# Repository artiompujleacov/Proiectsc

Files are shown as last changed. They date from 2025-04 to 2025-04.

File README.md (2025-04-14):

# README - OpenBook E-Reader

**Autor: Artiom Pujleacov**

## Prezentare Generală

OpenBook este un dispozitiv e-reader open-source, bazat pe microcontrollerul ESP32-C6. Acesta integrează un ecran e-paper de 7.5 inch, senzori de mediu (BME680), un sistem de gestionare a bateriei și conectivitate prin Wi-Fi și USB-C. Acest document oferă detalii despre arhitectura hardware, componentele utilizate și conexiunile lor.

---

## Diagramă de Bloc



# Lista de componente

| Cantitate | Componentă | Valoare | Descriere | Carcasă | Reper | Link Cumpărare | Datasheet |
|---|---|---|---|---|---|---|---|
| 1 | ADAFRUIT_LEDCHIP-LED0603 | - | LED | ADAFRUIT_CHIP-LED0603 | CHG_LED | [link](https://www.mouser.com/ProductDetail/Adafruit/CHIP-LED0603) | [datasheet](https://www.mouser.com/datasheet/2/737/CHIP-LED0603-1877199.pdf) |
| 1 | SJ | - | SMD solder JUMPER | SJ | SJ1 | [link](https://www.mouser.com/ProductDetail/TE-Connectivity/1-2176091-2) | [datasheet](https://www.mouser.com/datasheet/2/418/1-2176091-2-1817091.pdf) |
| 1 | ESP32_WROVER_EAGLE-LTSPICE_RR0402  | 0.47Ω | Rezistor | ESP32_WROVER_EAGLE-LTSPICE_R0402| R3 | [link](https://www.mouser.com/ProductDetail/Vishay/CRCW04020047ZRT7) | [datasheet](https://www.mouser.com/datasheet/2/427/crcwce-1764191.pdf) |
| 1 | ESP32_WROVER_EAGLE-LTSPICE_RR0402  | 100KΩ | Rezistor | ESP32_WROVER_EAGLE-LTSPICE_R0402| R1_PWRUSB | [link](https://www.mouser.com/ProductDetail/Vishay/CRCW0402100KFKED) | [datasheet](https://www.mouser.com/datasheet/2/427/crcwce-1764191.pdf) |
| 8 | EAGLE-LTSPICE_CC0402 | 100nF | Condensator | EAGLE-LTSPICE_C0402 | C1, C2, C4_USB, C6, C8, C9, C10, C_DELAY | [link](https://www.mouser.com/ProductDetail/Murata/GRM155R71C104KA88D) | [datasheet](https://www.mouser.com/datasheet/2/281/GRM155R71C104KA88D-1767201.pdf) |
| 1 | RCL_CPOL-EUCT3528 | 100µF | Condensator polarizat | RCL_CT3528 | C3 | [link](https://www.mouser.com/ProductDetail/Panasonic/EEE-FK1V101P) | [datasheet](https://www.mouser.com/datasheet/2/315/EEE-FK1V101P-1526881.pdf) |
| 10 | ESP32_WROVER_EAGLE-LTSPICE_RR0402  | 10KΩ | Rezistor | ESP32_WROVER_EAGLE-LTSPICE_R0402| R1, R1-PINH, R1_PINH1, R2-PINH, R2_PINH1, R4, R_BOOT, R_CHANGE, R_CL1, R_RESET | [link](https://www.mouser.com/ProductDetail/Vishay/CRCW040210K0FKED) | [datasheet](https://www.mouser.com/datasheet/2/427/crcwce-1764191.pdf) |
| 6 | ESP32_WROVER_EAGLE-LTSPICE_RR0402  | 10kΩ | Rezistor | ESP32_WROVER_EAGLE-LTSPICE_R0402| R5, R6, R7, R8, R9, R10 | [link](https://www.mouser.com/ProductDetail/Vishay/CRCW040210K0FKED) | [datasheet](https://www.mouser.com/datasheet/2/427/crcwce-1764191.pdf) |
| 1 | EAGLE-LTSPICE_CC0402 | 10µF | Condensator | EAGLE-LTSPICE_C0402 | C7 | [link](https://www.mouser.com/ProductDetail/Murata/GRM155R61A106ME44D) | [datasheet](https://www.mouser.com/datasheet/2/281/GRM155R61A106ME44D-1767201.pdf) |
| 1 | 112A-TAAR-R03_ATTEND | - | Micro SD Card Socket, Push-Push Type | 112ATAARR03ATTEND | J4 | [link](https://www.mouser.com/ProductDetail/Attend/112A-TAAR-R03) | [datasheet](https://www.mouser.com/datasheet/2/828/112A-TAAR-R03-1222862.pdf) |
| 1 | ESP32_WROVER_EAGLE-LTSPICE_RR0402  | 15Ω | Rezistor | ESP32_WROVER_EAGLE-LTSPICE_R0402| R_CAPACITOR  | [link](https://www.mouser.com/ProductDetail/Vishay/CRCW040215R0FKED) | [datasheet](https://www.mouser.com/datasheet/2/427/crcwce-1764191.pdf) |
| 1 | EAGLE-LTSPICE_CC0402 | 1µF | Condensator | EAGLE-LTSPICE_C0402 | C5 | [link](https://www.mouser.com/ProductDetail/Murata/GRM155R61A105KE15D) | [datasheet](https://www.mouser.com/datasheet/2/281/GRM155R61A105KE15D-1767201.pdf) |
| 10 | EAGLE-LTSPICE_CC0402 | 1µF/50V | Condensator ceramic multi-strat | 0402 | EPD_C1, EPD_C2, EPD_C5, EPD_C6, EPD_C7, EPD_C8, EPD_C9, EPD_C10, EPD_C11, EPD_C12 | [link](https://www.mouser.com/ProductDetail/Murata-Electronics/GRM155R61A105KE15D) | [datasheet](https://www.mouser.com/datasheet/2/281/1/GRM155R61A105KE15_01A-1983730.pdf) |

---

## Detalii Hardware

### ESP32-C6-WROOM-1-N8

- **Rol**: Control principal, suport pentru conectivitate wireless și periferice.
- **Interfețe disponibile**:
  - SPI: Display e-paper, memorie Flash, card Micro SD.
  - I2C: Senzor BME680, monitorizare baterie (MAX17048), ceas RTC (DS3231).
  - GPIO: Interacțiune cu butoane și LED-uri.
  - UART: Debugging și conectivitate serială.
- **Specificații**: 160MHz, 512KB SRAM, 8MB Flash integrat.

### Display E-Paper

- **Caracteristici**: Dimensiune 7.5 inch, rezoluție 800x480 pixeli, contrast 8:1.
- **Conectivitate**: Utilizare prin interfață SPI cu linii dedicate pentru control și resetare.
- **Consum**: <50mA în timpul actualizării imaginii, aproape nul în mod standby.

### Senzor BME680

- **Funcționalitate**: Măsurători de temperatură, umiditate, presiune atmosferică și calitate a aerului.
- **Interfață**: Conectare prin magistrala I2C la 400kHz.
- **Consum**: Sub 1mA în activitate, sub 1µA în modul de repaus.

### Sistem de Alimentare

- **Baterie**: Li-Po de 2500mAh, 3.7V.
- **Încărcare**: Controlată de MCP73831 prin portul USB-C, cu o capacitate maximă de 1A.
- **Monitorizare**: Funcție asigurată de MAX17048, comunicare prin I2C.
- **Consum energetic**:
  - Activ (Wi-Fi + ecran actualizat): ~150mA.
  - Standby (doar ecran afișat): ~10mA.
  - Deep Sleep: Sub 50µA.
  - **Autonomie estimată**: Aproximativ o săptămână (~250 ore cu un consum mediu de 10mA).

### Butoane de Navigare

- Echipate cu butoane tactile Panasonic EVQPUJ02K, fiecare având o rezistență pull-up de 10KΩ.

### USB-C

- **Rol**: Funcționează atât pentru încărcare (5V/1A), cât și pentru transfer de date (USB 2.0).
- **Protecție**: Integrare de diode ESD (USBLC6-2SC6Y) pentru siguranță la supratensiune.

---

## Configurare Pini ESP32-C6

| **Pin ESP32-C6** | **Funcție** | **Componentă** | **Rol** |
|---|---|---|---|
| GPIO0 | BOOT_BUTTON | Buton | Mod boot la inițializare |
| GPIO1 | RESET_BUTTON | Buton | Reset manual |
| GPIO2 | CHANGE_BUTTON | Buton | Schimbare meniuri |
| GPIO3 | EPD_CS | Display E-Paper | Chip Select pentru SPI |
| GPIO4 | EPD_DC | Display E-Paper | Control Date/Comenzi |
| GPIO5 | EPD_RST | Display E-Paper | Reset display |
| GPIO6 | EPD_BUSY | Display E-Paper | Detectare stare refresh |
| GPIO7 | SPI_MOSI | Display, Flash, SD | Linii de date SPI |
| GPIO8 | SPI_MISO | Display, Flash, SD | Linie de date SPI (citire) |
| GPIO9 | SPI_SCK | Display, Flash, SD | Semnal de ceas SPI |
| GPIO10 | FLASH_CS | Memorie Flash | Chip Select pentru memorie |
| GPIO11 | SD_CS | Card Micro SD | Chip Select pentru card SD |
| GPIO12 | I2C_SDA | BME680, MAX17048, DS3231 | Linie de date pentru I2C |
| GPIO13 | I2C_SCL | BME680, MAX17048, DS3231 | Linie de ceas pentru I2C |
| GPIO14 | CHG_LED | LED | Indică procesul de încărcare |
| GPIO15 | UART_TX | Debugging | Transmitere date seriale |
| GPIO16 | UART_RX | Debugging | Recepție date seriale |
| GPIO17 | USB_D+ | USB-C | Linie de date USB pozitivă |
| GPIO18 | USB_D- | USB-C | Linie de date USB negativă |

**Notă**: Pinii sunt selectați conform specificațiilor ESP32-C6 și funcționalităților necesare dispozitivului OpenBook. Unele dintre aceștia sunt multifuncționali și pot fi reutilizați în diverse configurații.

---

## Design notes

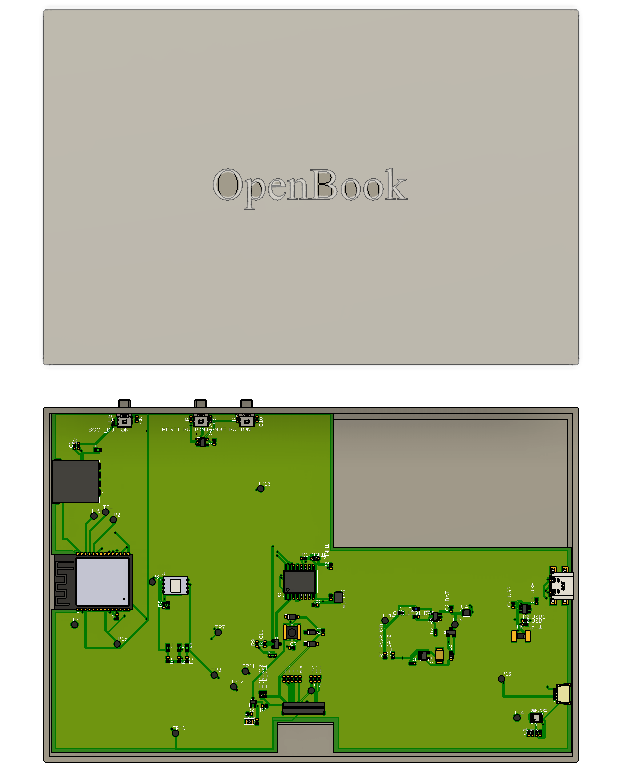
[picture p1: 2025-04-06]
Images/Screenshot 2025-04-06 195113.png

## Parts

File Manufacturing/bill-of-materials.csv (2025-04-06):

Qty | Value | Device | Package | Parts | Description | ARROW_PART_NUMBER | ARROW_PRICE-STOCK | AVAILABILITY | CENTROID_NOT_SPECIFIED | CHECK_PRICES | COPYRIGHT | DATASHEET | DESCRIPTION | DIGIKEY_DESCRIPTION | DIGIKEY_PART_NUMBER | HEIGHT | LEAD_FREE | MANUFACTURER_NAME | MANUFACTURER_PART_NUMBER | MF | MFR_NAME | MOUSER_PART_NUMBER | MOUSER_PRICE-STOCK | MOUSER_TESTING_PART_NUMBER | MOUSER_TESTING_PRICE-STOCK | MP | MPN | PACKAGE | POPULARITY | PREFIX | PRICE | PROD_ID | PURCHASE-URL | ROHS | SNAPEDA_LINK | SPICEMODEL | SPICEPREFIX | TEMPERATURE_RANGE_HIGH | TEMPERATURE_RANGE_LOW | TP_SIGNAL_NAME | VALUE
1 |  | ADAFRUIT_LEDCHIP-LED0603 | ADAFRUIT_CHIP-LED0603 | CHG_LED | LED
1 |  | SJ | SJ | SJ1 | SMD solder JUMPER |  |  |  |  |  |  |  |  |  |  |  |  |  |  |  |  |  |  |  |  |  |  |  | 3
1 | 0.1uF/50V | ESP32_WROVER_EAGLE-LTSPICE_CC0402 | ESP32_WROVER_EAGLE-LTSPICE_C0402 | EPD_C5 | CAPACITOR, European symbol |  |  |  |  |  |  |  |  |  |  |  |  |  |  |  |  |  |  |  |  |  |  |  |  |  |  |  |  |  |  | NONE | C
1 | 0.47 | ESP32_WROVER_EAGLE-LTSPICE_RR0402 | ESP32_WROVER_EAGLE-LTSPICE_R0402 | R3 | RESISTOR, European symbol |  |  |  |  |  |  |  |  |  |  |  |  |  |  |  |  |  |  |  |  |  |  |  |  |  |  |  |  |  |  | NONE | R
1 | 100K | ESP32_WROVER_EAGLE-LTSPICE_RR0402 | ESP32_WROVER_EAGLE-LTSPICE_R0402 | R1_PWRUSB | RESISTOR, European symbol |  |  |  |  |  |  |  |  |  |  |  |  |  |  |  |  |  |  |  |  |  |  |  |  |  |  |  |  |  |  | NONE | R
2 | 100nF | EAGLE-LTSPICE_CC0402 | EAGLE-LTSPICE_C0402 | C9, C_DELAY | CAPACITOR, European symbol |  |  |  |  |  |  |  |  |  |  |  |  |  |  |  |  |  |  |  |  |  |  |  |  |  |  |  |  |  |  | NONE | C
4 | 100nF | ESP32_WROVER_EAGLE-LTSPICE_CC0402 | ESP32_WROVER_EAGLE-LTSPICE_C0402 | C1, C2, C4_USB, C8 | CAPACITOR, European symbol |  |  |  |  |  |  |  |  |  |  |  |  |  |  |  |  |  |  |  |  |  |  |  |  |  |  |  |  |  |  | NONE | C
2 | 100uF | ESP32_WROVER_EAGLE-LTSPICE_CC0402 | ESP32_WROVER_EAGLE-LTSPICE_C0402 | C6, C10 | CAPACITOR, European symbol |  |  |  |  |  |  |  |  |  |  |  |  |  |  |  |  |  |  |  |  |  |  |  |  |  |  |  |  |  |  | NONE | C
1 | 100uF TANT | RCL_CPOL-EUCT3528 | RCL_CT3528 | C3 | POLARIZED CAPACITOR, European symbol |  |  |  |  |  |  |  |  |  |  |  |  |  |  |  |  |  |  |  |  |  |  |  | 0 |  |  |  |  |  |  |  | C
12 | 10K | ESP32_WROVER_EAGLE-LTSPICE_RR0402 | ESP32_WROVER_EAGLE-LTSPICE_R0402 | R1-PINH, R1-PINH1, R2-PINH, R2-PINH1, R5, R6, R7, R8, R9, R10, R_CHANGE, R_CL1 | RESISTOR, European symbol |  |  |  |  |  |  |  |  |  |  |  |  |  |  |  |  |  |  |  |  |  |  |  |  |  |  |  |  |  |  | NONE | R
4 | 10k | ESP32_WROVER_EAGLE-LTSPICE_RR0402 | ESP32_WROVER_EAGLE-LTSPICE_R0402 | R1, R4, R_BOOT, R_RESET | RESISTOR, European symbol |  |  |  |  |  |  |  |  |  |  |  |  |  |  |  |  |  |  |  |  |  |  |  |  |  |  |  |  |  |  | NONE | R
1 | 10uF | ESP32_WROVER_EAGLE-LTSPICE_CC0402 | ESP32_WROVER_EAGLE-LTSPICE_C0402 | C7 | CAPACITOR, European symbol |  |  |  |  |  |  |  |  |  |  |  |  |  |  |  |  |  |  |  |  |  |  |  |  |  |  |  |  |  |  | NONE | C
1 | 112A-TAAR-R03_ATTEND | 112A-TAAR-R03_ATTEND | 112ATAARR03ATTEND | J1 | Micro SD Card Socket, Push-Push Type, Top Mount, SMT, H=1.83mm, 10u |  |  |  |  |  |  |  | Micro SD Card Socket | Push-Push Type | Top Mount | SMT | H=1.83mm | 10u |  |  | 1.9mm |  | ATTEND | 112A-TAAR-R03 ATTEND
1 | 15 | ESP32_WROVER_EAGLE-LTSPICE_RR0402 | ESP32_WROVER_EAGLE-LTSPICE_R0402 | R_CAPACITOR | RESISTOR, European symbol |  |  |  |  |  |  |  |  |  |  |  |  |  |  |  |  |  |  |  |  |  |  |  |  |  |  |  |  |  |  | NONE | R
1 | 1uF | ESP32_WROVER_EAGLE-LTSPICE_CC0402 | ESP32_WROVER_EAGLE-LTSPICE_C0402 | C5 | CAPACITOR, European symbol |  |  |  |  |  |  |  |  |  |  |  |  |  |  |  |  |  |  |  |  |  |  |  |  |  |  |  |  |  |  | NONE | C
9 | 1uF/50V | ESP32_WROVER_EAGLE-LTSPICE_CC0402 | ESP32_WROVER_EAGLE-LTSPICE_C0402 | EPD_C1, EPD_C2, EPD_C6, EPD_C7, EPD_C8, EPD_C9, EPD_C10, EPD_C11, EPD_C12 | CAPACITOR, European symbol |  |  |  |  |  |  |  |  |  |  |  |  |  |  |  |  |  |  |  |  |  |  |  |  |  |  |  |  |  |  | NONE | C
1 | 2.2 | ESP32_WROVER_EAGLE-LTSPICE_RR0402 | ESP32_WROVER_EAGLE-LTSPICE_R0402 | R2 | RESISTOR, European symbol |  |  |  |  |  |  |  |  |  |  |  |  |  |  |  |  |  |  |  |  |  |  |  |  |  |  |  |  |  |  | NONE | R
1 | 200 | ESP32_WROVER_EAGLE-LTSPICE_RR0402 | ESP32_WROVER_EAGLE-LTSPICE_R0402 | R1_BAT | RESISTOR, European symbol |  |  |  |  |  |  |  |  |  |  |  |  |  |  |  |  |  |  |  |  |  |  |  |  |  |  |  |  |  |  | NONE | R
2 | 20V/4.2A/52mO/1.4W | ESP32_WROVER_SPARKFUN-DISCRETESEMI_MOSFET_PCH-DMG2305UX-7 | ESP32_WROVER_SPARKFUN-DISCRETESEMI_SOT23-3 | Q1, Q2 | P-channel MOSFETs |  |  |  |  |  |  |  |  |  |  |  |  |  |  |  |  |  |  |  |  |  |  |  |  |  |  | TRAN-14388 |  |  |  |  |  |  |  |  | 20V/4.2A/52mO/1.4W
1 | 2K | ESP32_WROVER_EAGLE-LTSPICE_RR0402 | ESP32_WROVER_EAGLE-LTSPICE_R0402 | R2_BAT | RESISTOR, European symbol |  |  |  |  |  |  |  |  |  |  |  |  |  |  |  |  |  |  |  |  |  |  |  |  |  |  |  |  |  |  | NONE | R
2 | 4.7uF | EAGLE-LTSPICE_CC0402 | EAGLE-LTSPICE_C0402 | C1_BAT1, C1_BAT2 | CAPACITOR, European symbol |  |  |  |  |  |  |  |  |  |  |  |  |  |  |  |  |  |  |  |  |  |  |  |  |  |  |  |  |  |  | NONE | C
3 | 4.7uF | ESP32_WROVER_EAGLE-LTSPICE_CC0402 | ESP32_WROVER_EAGLE-LTSPICE_C0402 | C1_BAT, C2_BAT, C5_USB | CAPACITOR, European symbol |  |  |  |  |  |  |  |  |  |  |  |  |  |  |  |  |  |  |  |  |  |  |  |  |  |  |  |  |  |  | NONE | C
1 | 4.7uF/25V | ESP32_WROVER_EAGLE-LTSPICE_CC0402 | ESP32_WROVER_EAGLE-LTSPICE_C0402 | C4 | CAPACITOR, European symbol |  |  |  |  |  |  |  |  |  |  |  |  |  |  |  |  |  |  |  |  |  |  |  |  |  |  |  |  |  |  | NONE | C
2 | 5k1 | ESP32_WROVER_EAGLE-LTSPICE_RR0402 | ESP32_WROVER_EAGLE-LTSPICE_R0402 | R2-USB, R2-USB1 | RESISTOR, European symbol |  |  |  |  |  |  |  |  |  |  |  |  |  |  |  |  |  |  |  |  |  |  |  |  |  |  |  |  |  |  | NONE | R
1 | 68uH | 744043680IND_4828-WE-TPC_WRE | IND_4828-WE-TPC_WRE | L1 |  |  |  |  |  |  | Copyright (C) 2024 Ultra Librarian. All rights reserved. |  |  |  |  |  |  |  | 744043680 |  | Wurth Electronics
1 | BD5229G-TR | BD5229G-TR | SOT95P280X125-5N | IC1 | Voltage Detector with Adjustable Delay Time: CMOS processes are utilized to develop high precision, low current consumption CMOS reset ICs that allow arbitrary setting of the delay time. The extensive lineup includes both Nch Open Drain and CMOS output types in a wide range of detection voltages (from 2.3V to 6.0V, in 0.1V steps), enabling selection of the ideal solution based on customer requirements. In addition, the entire series is of course both lead-free and RoHS-compliant. |  |  |  |  |  |  |  | Voltage Detector with Adjustable Delay Time: CMOS processes are utilized to develop high precision | low current consumption CMOS reset ICs that allow arbitrary setting of the delay time. The extensive lineup includes both Nch Open Drain and CMOS output types in a wide range of detection voltages (from 2.3V to 6.0V | in 0.1V steps) | enabling selection of the ideal solution based on customer requirements. In addition | the entire series is of course both lead-free and RoHS-compliant. |  |  | 1.25mm |  | ROHM Semiconductor | BD5229G-TR |  |  | 755-BD5229G-TR | https://www.mouser.co.uk/ProductDetail/ROHM-Semiconductor/BD5229G-TR?qs=4kLU8WoGk0vvnhrrYwdszw%3D%3D
3 | BUTTON_CUSYOMV1 | BUTTON_CUSYOMV1 | MYBUTTON | BOOT_BUTTON, CHANGE_BUTTON, RESET_BUTTON
1 | CPH3225A | CPH3225A | CAPCP3225X100N | C10_SUPERCAP | Cap 0.011F 3.3V 1210 Flat Check availability |  |  | Not in stock |  | https://www.snapeda.com/parts/CPH3225A/Seiko+Instruments/view-part/?ref=eda |  |  | 11 mF (EDLC) Supercapacitor 3.3 V 1210 (3225 Metric) - - |  |  |  |  |  |  | Seiko Instruments |  |  |  |  |  | CPH3225A |  | 1210 Seiko |  |  | None |  | https://www.snapeda.com/api/url_track_click_mouser/?unipart_id=562593&manufacturer=Seiko Instruments&part_name=CPH3225A&search_term=None |  | https://www.snapeda.com/parts/CPH3225A/Seiko+Instruments/view-part/?ref=snap
1 | DS3231SN# | DS3231SN# | SOIC127P1032X265-16N | U3 | Real Time Clock Serial 16-Pin SOIC W T/R Check availability |  |  | In Stock |  | https://www.snapeda.com/parts/DS3231SN%23/Analog+Devices/view-part/?ref=eda |  |  | Extremely Accurate I²C-Integrated RTC/TCXO/Crystal |  |  |  |  |  |  | Analog Devices |  |  |  |  |  | DS3231SN# |  | SOIC-16 Maxim |  |  | None |  | https://www.snapeda.com/api/url_track_click_mouser/?unipart_id=99048&manufacturer=Analog Devices&part_name=DS3231SN#&search_term=None |  | https://www.snapeda.com/parts/DS3231SN%23/Analog+Devices/view-part/?ref=snap
1 | ESP32-C6-WROOM-1-N8 | ESP32-C6-WROOM-1-N8 | XCVR_ESP32-C6-WROOM-1-N8 | U2 | Check availability |  |  | In Stock |  | https://www.snapeda.com/parts/ESP32-C6-WROOM-1-N8/Espressif+Systems/view-part/?ref=eda |  |  | Multiprotocol Modules ESP32-C6 module | Wi-Fi 6 in 2.4 GHz band | Bluetooth 5 | Zigbee 3.0 and Thread. ESP34-WROOM Compatible - ENGINEERING SAMPLE |  |  |  |  |  |  | Espressif Systems |  |  |  |  |  | ESP32-C6-WROOM-1-N8 |  | None |  |  | None |  |  |  | https://www.snapeda.com/parts/ESP32-C6-WROOM-1-N8/Espressif+Systems/view-part/?ref=snap
1 | ESP32C6_VARISTORCN1812 | ESP32C6_VARISTORCN1812 | ESP32C6_VARISTOR_CT/CN1812 | PFMF.050.1 | VARISTOR |  |  |  |  |  |  |  |  |  |  |  |  |  |  |  |  |  |  |  |  |  |  |  | 0
2 | ESP32_WROVER_AVX---SD0805S020S1R0_AVX_SD0805S020S1R0_0_0AVX_SD0805S020S1R0_0_0 | ESP32_WROVER_AVX---SD0805S020S1R0_AVX_SD0805S020S1R0_0_0AVX_SD0805S020S1R0_0_0 | ESP32_WROVER_AVX---SD0805S020S1R0_AVX_SD0805S020S1R0_0 | D2, D7 | Schottky Barrier Rectifier Diode |  |  |  | No |  |  | http://datasheets.avx.com/schottky.pdf |  | DIODE SCHOTTKY 20V 1A 0805 | 478-7800-1-ND |  | yes |  |  | AVX |  | 581-SD0805S020S1R0 |  |  |  |  |  | 0805 (2012 metric) |  | D |  |  |  | yes |  |  |  | +125°C | -55°C
1 | ESP32_WROVER_BME680_BME680 | ESP32_WROVER_BME680_BME680 | ESP32_WROVER_BME680_PSON80P300X300X100-8N | SENSOR2 | Integrated Environmental Unit |  |  | Unavailable |  |  |  |  | Integrated Environmental Unit |  |  |  |  |  |  | Bosch Sensortec |  |  |  |  |  | BME680 |  | LGA-8 Bosch Tools |  |  | None
1 | ESP32_WROVER_SPARKFUN-IC-POWER_MCP73831 | ESP32_WROVER_SPARKFUN-IC-POWER_MCP73831 | ESP32_WROVER_SPARKFUN-IC-POWER_SOT23-5 | MCP73831 | MCP73831T Li-Ion, Li-Pol Controller |  |  |  |  |  |  |  |  |  |  |  |  |  |  |  |  |  |  |  |  |  |  |  |  |  |  | IC-09995
1 | FH34SRJ-24S-0.5SH_99_ | FH34SRJ-24S-0.5SH_99_ | FH34SRJ24S05SH99 | J3 | (0.50mm) Surface Mount, Right Angle |  |  |  |  |  |  |  | 24 Position FFC | FPC Connector Contacts | (0.50mm) Surface Mount | Right Angle |  |  | 1.1mm |  | Hirose | FH34SRJ-24S-0.5SH(99) |  |  | 798-FH34SRJ24S05SH99 | https://www.mouser.co.uk/ProductDetail/Hirose-Connector/FH34SRJ-24S-0.5SH99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
1 | MAX17048G+T10 | MAX17048G+T10 | SON50P200X200X80-9N | U4 | Check availability |  |  | In Stock |  | https://www.snapeda.com/parts/MAX17048G+T10/Analog+Devices/view-part/?ref=eda |  |  | 3µA 1-Cell/2-Cell Fuel Gauge with ModelGauge |  |  |  |  |  |  | Analog Devices |  |  |  |  |  | MAX17048G+T10 |  | TDFN-8 Maxim |  |  | None |  | https://www.snapeda.com/api/url_track_click_mouser/?unipart_id=329239&manufacturer=Analog Devices&part_name=MAX17048G+T10&search_term=None |  | https://www.snapeda.com/parts/MAX17048G+T10/Analog+Devices/view-part/?ref=snap
3 | MBR0530 | MBR0530 | SOD3716X135N | D3, D4, D5 | ON SEMICONDUCTOR - MBR0530 - DIODE, SCHOTTKY, 0.5A, 30V, SOD-123 |  |  | In Stock |  | https://www.snapeda.com/parts/MBR0530/Onsemi/view-part/?ref=eda |  |  | Diode Schottky 30 V 500mA Surface Mount SOD-123 |  |  |  |  |  |  | ON Semiconductor |  |  |  |  |  | MBR0530 |  | SOD-123-2 ON Semiconductor |  |  | None |  | https://www.snapeda.com/api/url_track_click_mouser/?unipart_id=179458&manufacturer=ON Semiconductor&part_name=MBR0530&search_term=None |  | https://www.snapeda.com/parts/MBR0530/Onsemi/view-part/?ref=snap
6 | PGB1010603MR | PGB1010603MR | DIOC1608X36N | D6, D8, D9, D10, D11, D12 | Check availability |  |  | In Stock |  | https://www.snapeda.com/parts/PGB1010603MR/Littelfuse/view-part/?ref=eda |  |  | 150V (Typ) Clamp - Ipp Tvs Diode Surface Mount 0603 (1608 Metric) |  |  |  |  |  |  | Littelfuse Inc. |  |  |  |  |  | PGB1010603MR |  | 0603 Littelfuse Inc. |  |  | None |  | https://www.snapeda.com/api/url_track_click_mouser/?unipart_id=5659453&manufacturer=Littelfuse Inc.&part_name=PGB1010603MR&search_term=None |  | https://www.snapeda.com/parts/PGB1010603MR/Littelfuse/view-part/?ref=snap
1 | QWIIC_RIGHT_ANGLE | QWIIC_CONNECTORJS-1MM | JST04_1MM_RA | J4 | SparkFun I2C Standard Qwiic Connector |  |  |  |  |  |  |  |  |  |  |  |  |  |  |  |  |  |  |  |  |  |  |  |  |  |  | CONN-13694 |  |  |  |  |  |  |  |  | QWIIC_RIGHT_ANGLE
1 | SAMACSYS_PARTS_USB4110-GF-A | SAMACSYS_PARTS_USB4110-GF-A | SAMACSYS_PARTS_USB4110GFA | J2 | CONN USB 2.0 TYPE-C R/A SMT |  |  |  |  |  |  |  | CONN USB 2.0 TYPE-C R/A SMT |  |  | 3.26mm |  | GCT (GLOBAL CONNECTOR TECHNOLOGY) | USB4110-GF-A |  |  | 640-USB4110-GF-A | https://www.mouser.co.uk/ProductDetail/GCT/USB4110-GF-A?qs=KUoIvG%2F9IlYiZvIXQjyJeA%3D%3D
1 | SI1308EDL-T1-GE3 | SI1308EDL-T1-GE3 | SOT65P210X110-3N | Q3 | MOSFET N-Ch 30V 1.5A TrenchFET SC70 Vishay Si1308EDL-T1-GE3 N-channel MOSFET Transistor, 1.5 A, 30 V, 3-Pin SC-70 |  |  | In Stock |  | https://www.snapeda.com/parts/SI1308EDL-T1-GE3/Vishay+Siliconix/view-part/?ref=eda |  |  | Si1308EDL-T1-GE3 N-channel MOSFET Transistor | 1.5 A | 30 V | 3-Pin SC-70 | Siliconix / Vishay SI1308EDL-T1-GE3 |  |  |  |  |  |  | Vishay Siliconix |  |  |  |  |  | SI1308EDL-T1-GE3 |  | SOT-323 Vishay Semiconductor |  |  | None |  | https://www.snapeda.com/api/url_track_click_mouser/?unipart_id=274603&manufacturer=Vishay Siliconix&part_name=SI1308EDL-T1-GE3&search_term=None |  | https://www.snapeda.com/parts/SI1308EDL-T1-GE3/Vishay+Siliconix/view-part/?ref=snap
17 | TPTP20R | TPTP20R | TP20R | TP1, TP2, TP3, TP4, TP5, TP6, TP7, TP8, TP9, TP10, TP11, TP12, TP13, TP14, TP15, TP16, TP17 | Test pad |  |  |  |  |  |  |  |  |  |  |  |  |  |  |  |  |  |  |  |  |  |  |  | 2
1 | USBLC6-2SC6Y | USBLC6-2SC6Y | SOT95P280X145-6N | D1 | Low Cap. ESD Protection Auto SOT-23-6 STMicroelectronics USBLC6-2SC6Y, Dual Uni-Directional TVS Diode Array, 6-Pin SOT-23 |  |  | In Stock |  | https://www.snapeda.com/parts/USBLC6-2SC6Y/STMicroelectronics/view-part/?ref=eda |  |  | 17V Clamp 5A (8/20µs) Ipp Tvs Diode Surface Mount SOT-23-6 |  |  |  |  |  |  | STMicroelectronics |  |  |  |  |  | USBLC6-2SC6Y |  | SOT-23-6 STMicroelectronics |  |  | None |  |  |  | https://www.snapeda.com/parts/USBLC6-2SC6Y/STMicroelectronics/view-part/?ref=snap
1 | W25Q512JVEIQ | W25Q512JVEIQ | SON127P600X800X80-9N | U1 | Check availability |  |  | In Stock |  | https://www.snapeda.com/parts/W25Q512JVEIQ/Winbond+Electronics/view-part/?ref=eda |  |  | FLASH - NOR Memory IC 512Mb (64M x 8) SPI - Quad I/O 133 MHz 8-WSON (8x6) |  |  |  |  |  |  | Winbond Electronics |  |  |  |  |  | W25Q512JVEIQ |  | Package |  |  | None |  |  |  | https://www.snapeda.com/parts/W25Q512JVEIQ/Winbond+Electronics/view-part/?ref=snap
1 | XC6220A331MR-G | XC6220A331MR-G | SOT95P280X120-5N | IC4 | LDO Voltage Regulators |  |  |  |  |  |  |  | LDO Voltage Regulators |  |  | 1.2mm |  | Torex | XC6220A331MR-G |  |  | 865-XC6220A331MR-G | https://www.mouser.co.uk/ProductDetail/Torex-Semiconductor/XC6220A331MR-G?qs=AsjdqWjXhJ8ZSWznL1J0gg%3D%3D

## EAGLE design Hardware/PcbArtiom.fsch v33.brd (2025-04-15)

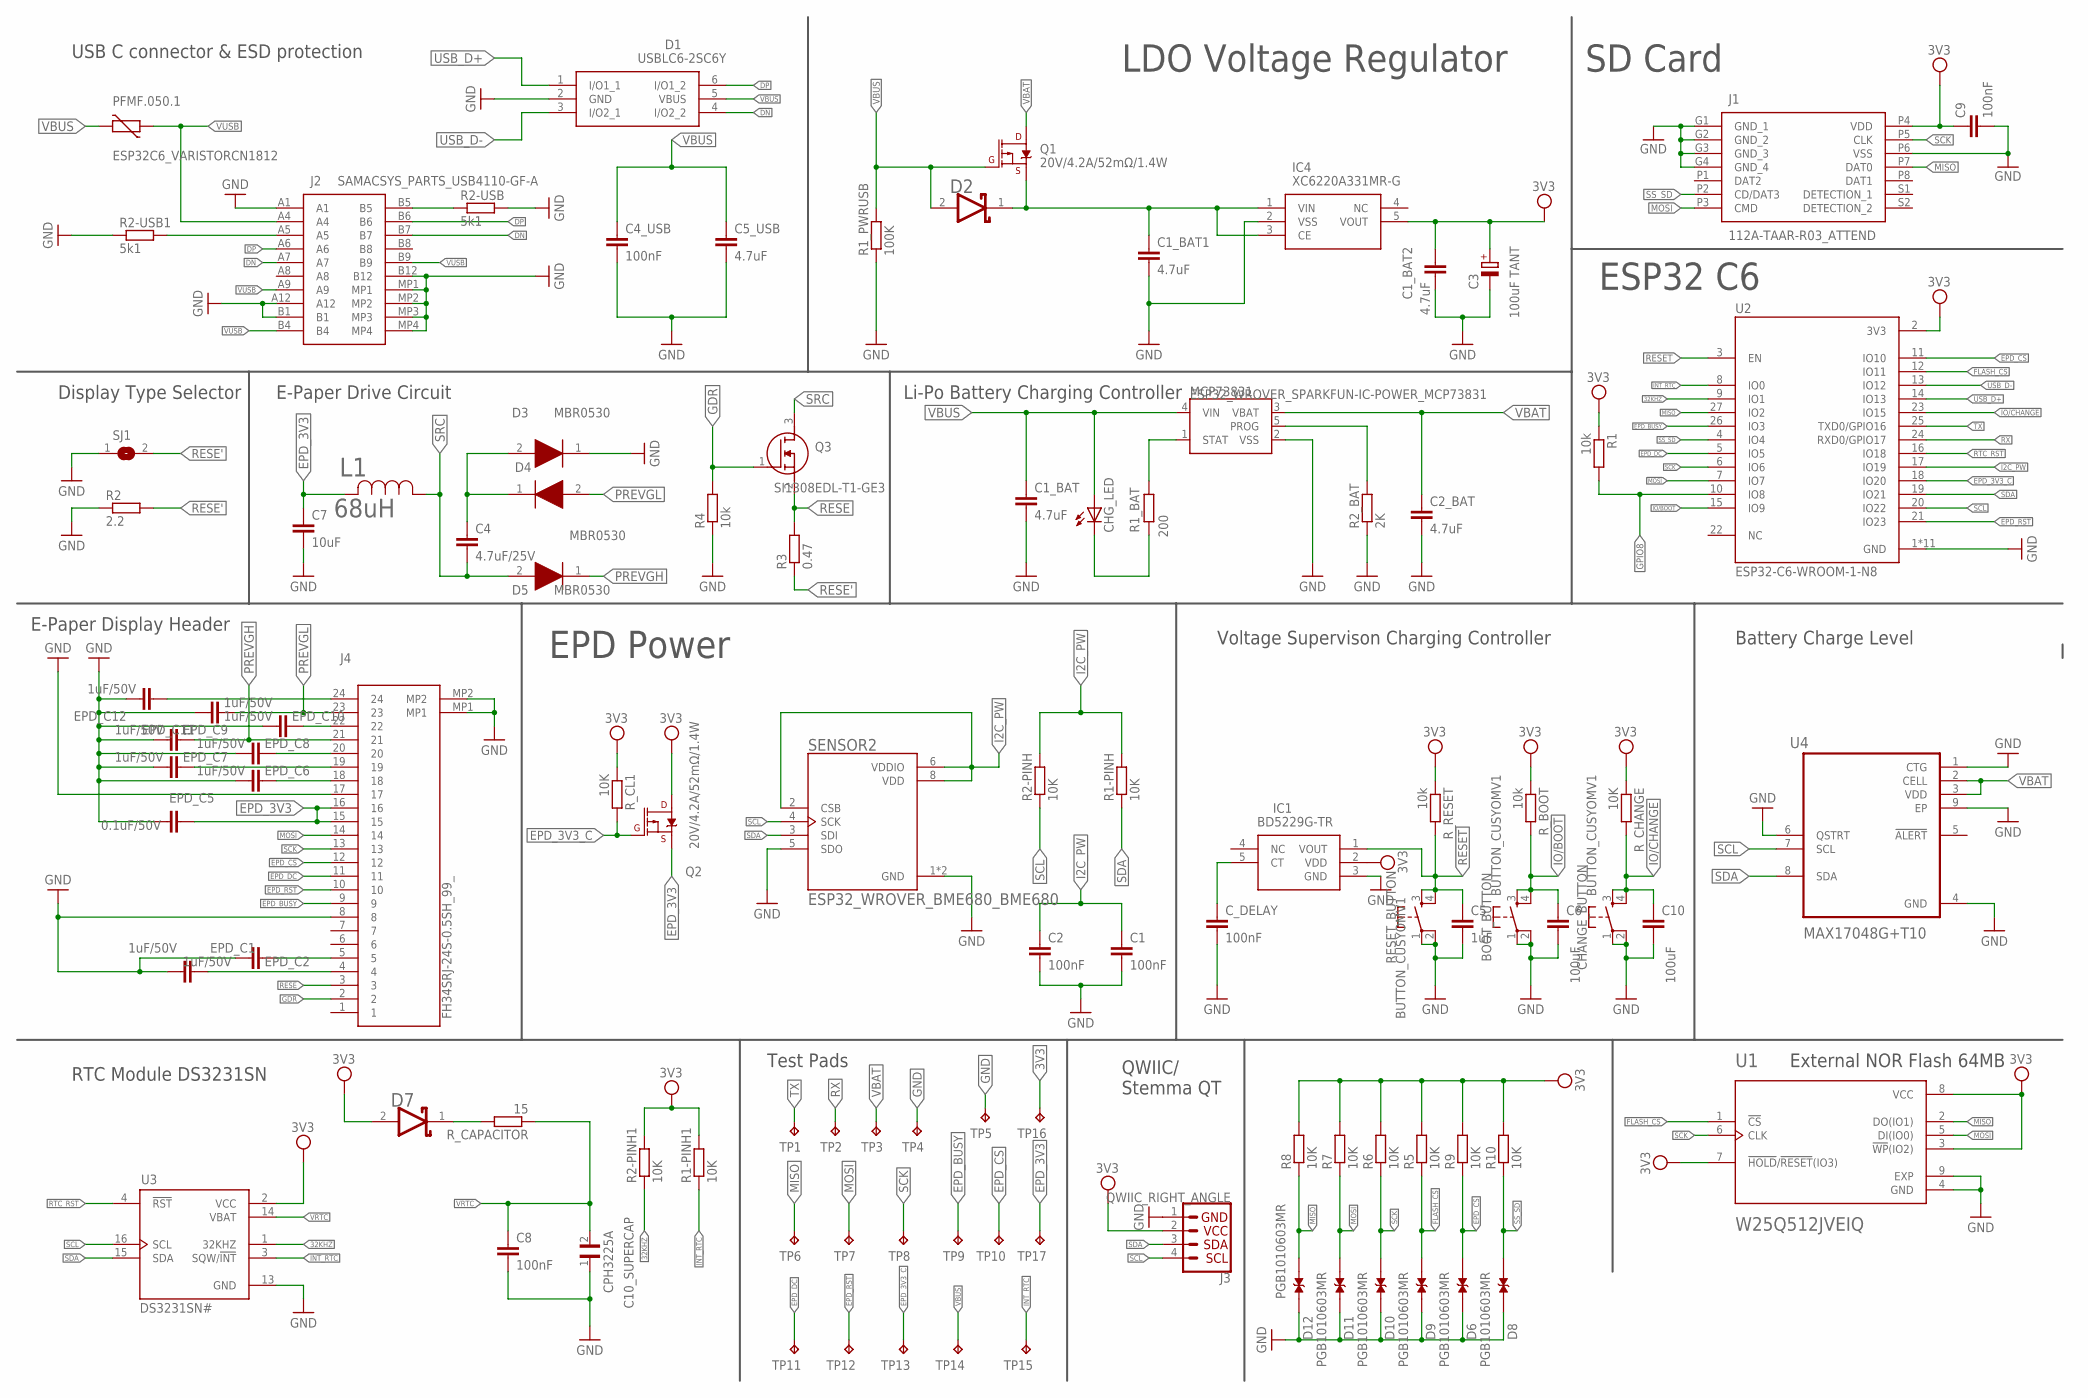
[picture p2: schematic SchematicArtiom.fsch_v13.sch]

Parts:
BOOT_BUTTON: BUTTON_CUSYOMV1; MYBUTTON
C1, C2, C4_USB, C8: 100nF; ESP32_WROVER_EAGLE-LTSPICE_C0402
C1_BAT, C2_BAT, C5_USB: 4.7uF; ESP32_WROVER_EAGLE-LTSPICE_C0402
C1_BAT1, C1_BAT2: 4.7uF; EAGLE-LTSPICE_C0402
C3: 100uF TANT; RCL_CT3528
C4: 4.7uF/25V; ESP32_WROVER_EAGLE-LTSPICE_C0402
C5: 1uF; ESP32_WROVER_EAGLE-LTSPICE_C0402
C6, C10: 100uF; ESP32_WROVER_EAGLE-LTSPICE_C0402
C7: 10uF; ESP32_WROVER_EAGLE-LTSPICE_C0402
C9: 100nF; EAGLE-LTSPICE_C0402
C10_SUPERCAP: CPH3225A; CAPCP3225X100N
CHANGE_BUTTON: BUTTON_CUSYOMV1; MYBUTTON
CHG_LED: ADAFRUIT_LEDCHIP-LED0603; ADAFRUIT_CHIP-LED0603
C_DELAY: 100nF; EAGLE-LTSPICE_C0402
D1: USBLC6-2SC6Y; SOT95P280X145-6N
D2, D7: ESP32_WROVER_AVX---SD0805S020S1R0_AVX_SD0805S020S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; ESP32_WROVER_AVX---SD0805S020S1R0_AVX_SD0805S020S1R0_0
D3, D4, D5: MBR0530; SOD3716X135N
D6, D8, D9, D10, D11, D12: PGB1010603MR; DIOC1608X36N
EPD_C1, EPD_C2, EPD_C6, EPD_C7, EPD_C8, EPD_C9, EPD_C10, EPD_C11, EPD_C12: 1uF/50V; ESP32_WROVER_EAGLE-LTSPICE_C0402
EPD_C5: 0.1uF/50V; ESP32_WROVER_EAGLE-LTSPICE_C0402
IC1: BD5229G-TR; SOT95P280X125-5N
IC4: XC6220A331MR-G; SOT95P280X120-5N
J1: 112A-TAAR-R03_ATTEND; 112ATAARR03ATTEND
J2: SAMACSYS_PARTS_USB4110-GF-A; SAMACSYS_PARTS_USB4110GFA
J3: QWIIC_RIGHT_ANGLE; JST04_1MM_RA
J4: FH34SRJ-24S-0.5SH_99_; FH34SRJ24S05SH99
L1: 68uH; IND_4828-WE-TPC_WRE
MCP73831: ESP32_WROVER_SPARKFUN-IC-POWER_MCP73831; ESP32_WROVER_SPARKFUN-IC-POWER_SOT23-5
PFMF.050.1: ESP32C6_VARISTORCN1812; ESP32C6_VARISTOR_CT/CN1812
Q1, Q2: 20V/4.2A/52mΩ/1.4W; ESP32_WROVER_SPARKFUN-DISCRETESEMI_SOT23-3
Q3: SI1308EDL-T1-GE3; SOT65P210X110-3N
R1, R4: 10k; ESP32_WROVER_EAGLE-LTSPICE_R0402
R1-PINH, R1-PINH1, R2-PINH, R2-PINH1, R5, R6, R7, R8, R9, R10: 10K; ESP32_WROVER_EAGLE-LTSPICE_R0402
R1_BAT: 200; ESP32_WROVER_EAGLE-LTSPICE_R0402
R1_PWRUSB: 100K; ESP32_WROVER_EAGLE-LTSPICE_R0402
R2: 2.2; ESP32_WROVER_EAGLE-LTSPICE_R0402
R2-USB, R2-USB1: 5k1; ESP32_WROVER_EAGLE-LTSPICE_R0402
R2_BAT: 2K; ESP32_WROVER_EAGLE-LTSPICE_R0402
R3: 0.47; ESP32_WROVER_EAGLE-LTSPICE_R0402
RESET_BUTTON: BUTTON_CUSYOMV1; MYBUTTON
R_BOOT: 10k; ESP32_WROVER_EAGLE-LTSPICE_R0402
R_CAPACITOR: 15; ESP32_WROVER_EAGLE-LTSPICE_R0402
R_CHANGE: 10K; ESP32_WROVER_EAGLE-LTSPICE_R0402
R_CL1: 10K; ESP32_WROVER_EAGLE-LTSPICE_R0402
R_RESET: 10k; ESP32_WROVER_EAGLE-LTSPICE_R0402
SENSOR2: ESP32_WROVER_BME680_BME680; ESP32_WROVER_BME680_PSON80P300X300X100-8N
SJ1: SJ
TP1, TP2, TP3, TP4, TP5, TP6, TP7, TP8, TP9, TP10, TP11, TP12, TP13, TP14, TP15, TP16, TP17: TPTP20R; TP20R
U1: W25Q512JVEIQ; SON127P600X800X80-9N
U2: ESP32-C6-WROOM-1-N8; XCVR_ESP32-C6-WROOM-1-N8
U3: DS3231SN#; SOIC127P1032X265-16N
U4: MAX17048G+T10; SON50P200X200X80-9N

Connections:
3V3: C1_BAT2.1, C3.+, C9.1, D7.2 (ANODE), IC1.2 (VDD), IC4.5 (VOUT), J1.P4 (VDD), J3.2, Q2.3 (D), R1.1, R1-PINH1.2, R2-PINH1.2, R5.2, R6.2, R7.2, R8.2, R9.2, R10.2, R_BOOT.1, R_CHANGE.1, R_CL1.1, R_RESET.1, TP16.TP, U1.3 (!WP!(IO2)), U1.7 (!HOLD!/!RESET!(IO3)), U1.8 (VCC), U2.2 (3V3), U3.2 (VCC)
32KHZ: R2-PINH1.1, U2.9 (IO1), U3.1 (32KHZ)
DN: D1.4 (I/O2_2), J2.A7, J2.B7
DP: D1.6 (I/O1_2), J2.A6, J2.B6
EPD_3V3: C7.1, EPD_C5.1, J4.15, J4.16, L1.2, Q2.2 (S), TP17.TP
EPD_3V3_C: Q2.1 (G), R_CL1.2, TP13.TP, U2.18 (IO20)
EPD_BUSY: J4.9, TP9.TP, U2.26 (IO3)
EPD_CS: D6.2, J4.12, R9.1, TP10.TP, U2.11 (IO10)
EPD_DC: J4.11, TP11.TP, U2.5 (IO5)
EPD_RST: J4.10, TP12.TP, U2.21 (IO23)
FLASH_CS: D9.2, R5.1, U1.1 (!CS), U2.12 (IO11)
GDR: J4.2, Q3.1 (G), R4.2
GND: BOOT_BUTTON.1, BOOT_BUTTON.2, C1.2, C1_BAT.2, C1_BAT1.2, C1_BAT2.2, C2.2, C2_BAT.2, C3.-, C4_USB.2, C5.2, C5_USB.2, C6.2, C7.2, C8.2, C9.2, C10.2, C10_SUPERCAP.1, CHANGE_BUTTON.1, CHANGE_BUTTON.2, C_DELAY.2, D1.2 (GND), D3.1 (K), D6.1, D8.1, D9.1, D10.1, D11.1, D12.1, EPD_C1.2, EPD_C2.2, EPD_C5.2, EPD_C6.2, EPD_C7.2, EPD_C8.2, EPD_C9.2, EPD_C10.2, EPD_C11.2, EPD_C12.2, IC1.3 (GND), IC4.2 (VSS), J1.G1 (GND_1), J1.G2 (GND_2), J1.G3 (GND_3), J1.G4 (GND_4), J1.P6 (VSS), J2.A1, J2.A12, J2.B1, J2.B12, J2.MP1, J2.MP2, J2.MP3, J2.MP4, J3.1, J4.8, J4.17, J4.MP1, J4.MP2, MCP73831.2 (VSS), R1_PWRUSB.1, R2.1, R2-USB.2, R2-USB1.1, R2_BAT.1, R4.1, RESET_BUTTON.1, RESET_BUTTON.2, SENSOR2.1 (GND), SENSOR2.5 (SDO), SENSOR2.7 (GND), SJ1.1, TP4.TP, TP5.TP, U1.4 (GND), U1.9 (EXP), U2.1 (GND), U2.28 (GND), U2.29_1 (GND), U2.29_2 (GND), U2.29_3 (GND), U2.29_4 (GND), U2.29_5 (GND), U2.29_6 (GND), U2.29_7 (GND), U2.29_8 (GND), U2.29_9 (GND), U3.13 (GND), U4.1 (CTG), U4.4 (GND), U4.6 (QSTRT), U4.9 (EP)
GPIO8: R1.2, U2.10 (IO8)
I2C_PW: C1.1, C2.1, R1-PINH.2, R2-PINH.2, SENSOR2.2 (CSB), SENSOR2.6 (VDDIO), SENSOR2.8 (VDD), U2.17 (IO19)
INT_RTC: R1-PINH1.1, TP15.TP, U2.8 (IO0), U3.3 (SQW/!INT)
IO/BOOT: BOOT_BUTTON.3, BOOT_BUTTON.4, C6.1, R_BOOT.2, U2.15 (IO9)
IO/CHANGE: C10.1, CHANGE_BUTTON.3, CHANGE_BUTTON.4, R_CHANGE.2, U2.23 (IO15)
MISO: D12.2, J1.P7 (DAT0), R8.1, TP6.TP, U1.2 (DO(IO1)), U2.27 (IO2)
MOSI: D11.2, J1.P3 (CMD), J4.14, R7.1, TP7.TP, U1.5 (DI(IO0)), U2.7 (IO7)
unnamed: C1_BAT1.1, D2.1 (CATHODE), IC4.1 (VIN), IC4.3 (CE), Q1.2 (S)
unnamed: MCP73831.1 (STAT), R1_BAT.1
unnamed: CHG_LED.C, R1_BAT.2
unnamed: J2.B5, R2-USB.1
unnamed: MCP73831.5 (PROG), R2_BAT.2
unnamed: D7.1 (CATHODE), R_CAPACITOR.2
unnamed: C_DELAY.1, IC1.5 (CT)
unnamed: EPD_C2.1, J4.5
unnamed: J2.A5, R2-USB1.2
unnamed: EPD_C1.1, J4.4
unnamed: EPD_C6.1, J4.18
unnamed: EPD_C7.1, J4.19
unnamed: EPD_C8.1, J4.20
unnamed: EPD_C10.1, J4.22
unnamed: EPD_C12.1, J4.24
unnamed: C4.1, D3.2 (A), D4.1 (K)
PREVGH: D5.1 (K), EPD_C9.1, J4.21
PREVGL: D4.2 (A), EPD_C11.1, J4.23
RESE: J4.3, Q3.2 (S), R3.2
RESE': R2.2, R3.1, SJ1.2
RESET: C5.1, IC1.1 (VOUT), RESET_BUTTON.3, RESET_BUTTON.4, R_RESET.2, U2.3 (EN)
RTC_RST: U2.16 (IO18), U3.4 (!RST)
RX: TP2.TP, U2.24 (RXD0/GPIO17)
SCK: D10.2, J1.P5 (CLK), J4.13, R6.1, TP8.TP, U1.6 (CLK), U2.6 (IO6)
SCL: J3.4, R2-PINH.1, SENSOR2.4 (SCK), U2.20 (IO22), U3.16 (SCL), U4.7 (SCL)
SDA: J3.3, R1-PINH.1, SENSOR2.3 (SDI), U2.19 (IO21), U3.15 (SDA), U4.8 (SDA)
SRC: C4.2, D5.2 (A), L1.1, Q3.3 (D)
SS_SD: D8.2, J1.P2 (CD/DAT3), R10.1, U2.4 (IO4)
TX: TP1.TP, U2.25 (TXD0/GPIO16)
USB_D+: D1.1 (I/O1_1), U2.14 (IO13)
USB_D-: D1.3 (I/O2_1), U2.13 (IO12)
VBAT: C2_BAT.1, MCP73831.3 (VBAT), Q1.3 (D), TP3.TP, U4.2 (CELL), U4.3 (VDD)
VBUS: C1_BAT.1, C4_USB.1, C5_USB.1, CHG_LED.A, D1.5 (VBUS), D2.2 (ANODE), MCP73831.4 (VIN), PFMF.050.1.2, Q1.1 (G), R1_PWRUSB.2, TP14.TP
VRTC: C8.1, C10_SUPERCAP.2, R_CAPACITOR.1, U3.14 (VBAT)
VUSB: J2.A4, J2.A9, J2.B4, J2.B9, PFMF.050.1.1

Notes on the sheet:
SD Card
ESP32 C6
LDO Voltage Regulator
Li-Po Battery Charging Controller
E-Paper Drive Circuit
EPD Power
USB C connector & ESD protection
Display Type Selector
E-Paper Display Header
Voltage Supervison Charging Controller
Battery Charge Level
External NOR Flash 64MB
QWIIC/ Stemma QT
Test Pads
RTC Module DS3231SN

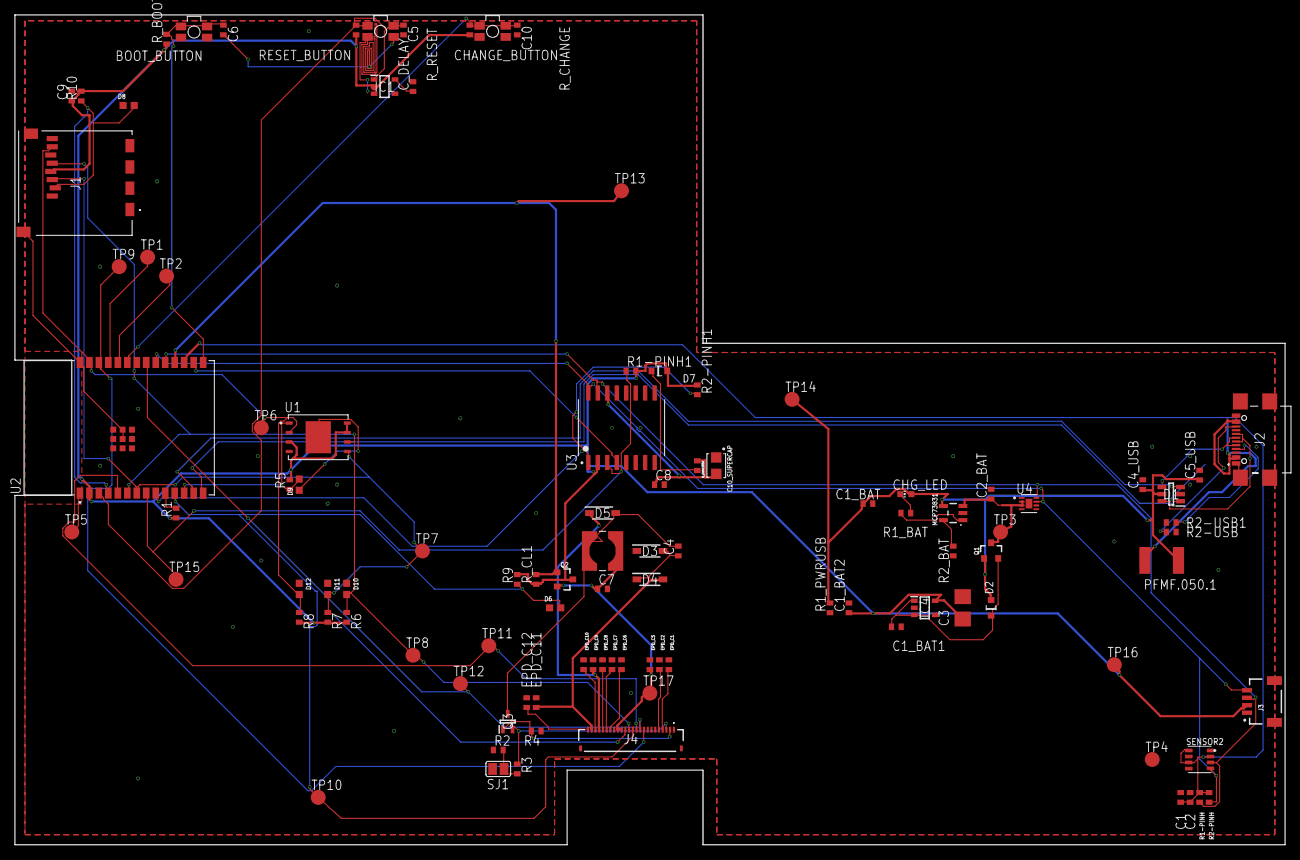
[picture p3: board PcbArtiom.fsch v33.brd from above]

Board: 2 copper layers, 170.2 x 111.2 mm, 103 parts (0 on the bottom side), 55 nets.

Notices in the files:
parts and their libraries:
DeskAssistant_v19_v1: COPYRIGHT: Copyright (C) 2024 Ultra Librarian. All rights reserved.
